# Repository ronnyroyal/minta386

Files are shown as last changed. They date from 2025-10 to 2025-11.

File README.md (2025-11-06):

# Minta 386 memory board

This is a reverse engineered memory board for the Minta Technologies PCB-305 Mainboard.  
https://theretroweb.com/motherboards/s/minta-technologies-co-pcb-305  
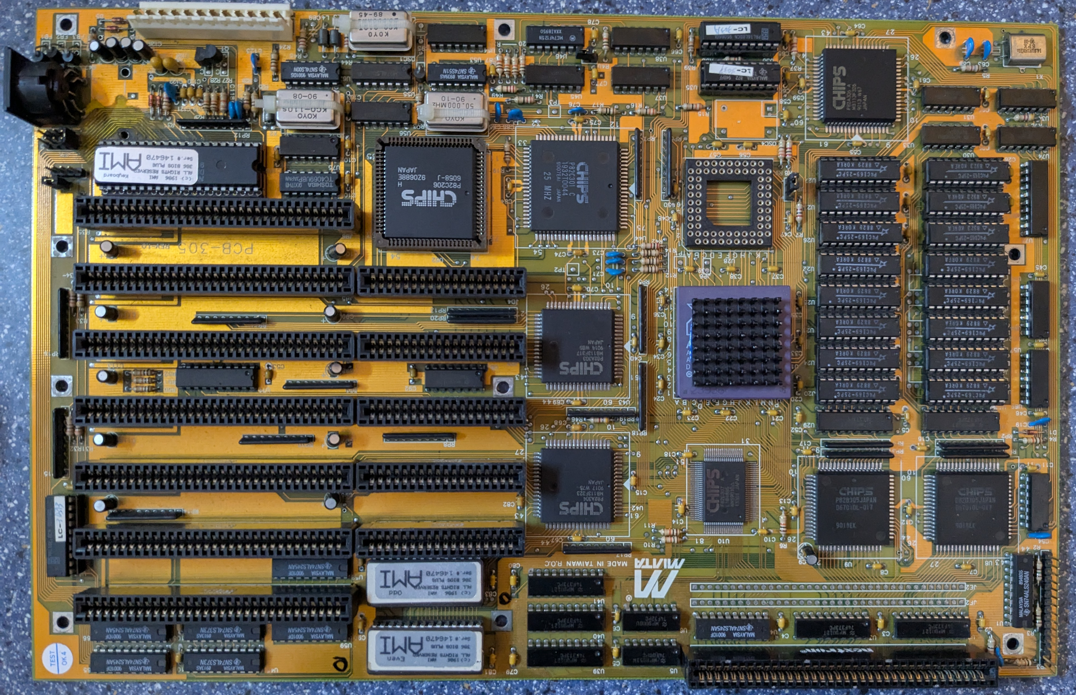
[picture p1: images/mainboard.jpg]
  
I bought this board a while ago missing it's proprietary memory board with the plan to reverse engineer the memory board.   
The memory card was designed with sipp memory in mind as i have a lot of sipp modules, but the spacing also allows for simm sockets to be installed.
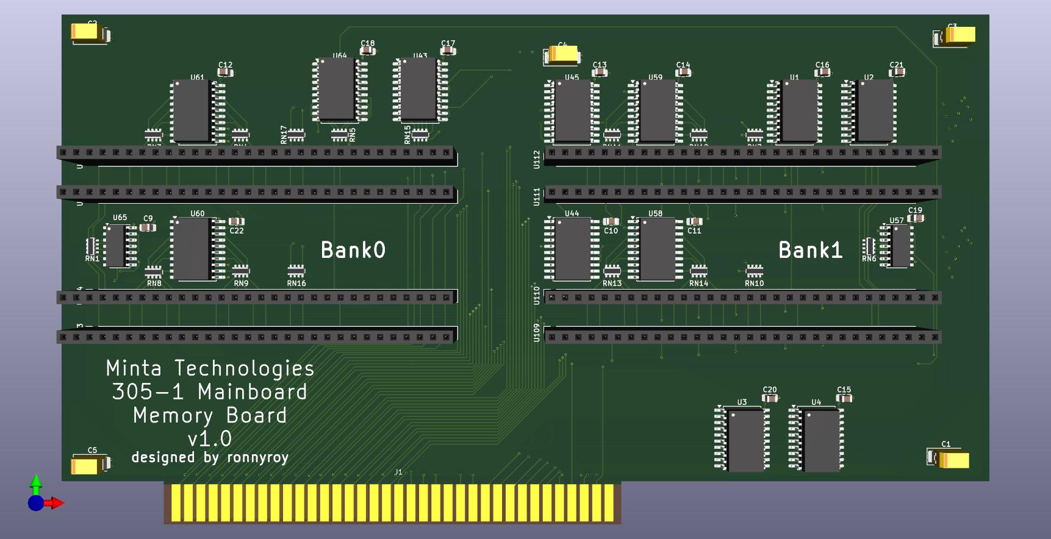
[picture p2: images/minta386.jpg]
 
It can accomodate up to 8 1MB modules with the slot being wired to theoretically support up to 16MB.  
The first PCB revision contains a fault with the parity bit lines being swapped. This is fixed in the provided files.
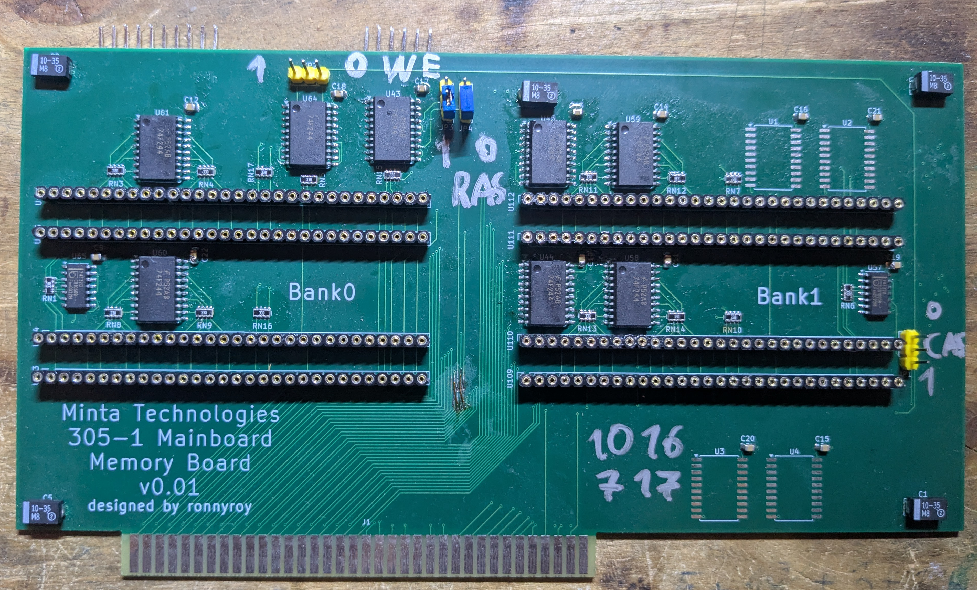
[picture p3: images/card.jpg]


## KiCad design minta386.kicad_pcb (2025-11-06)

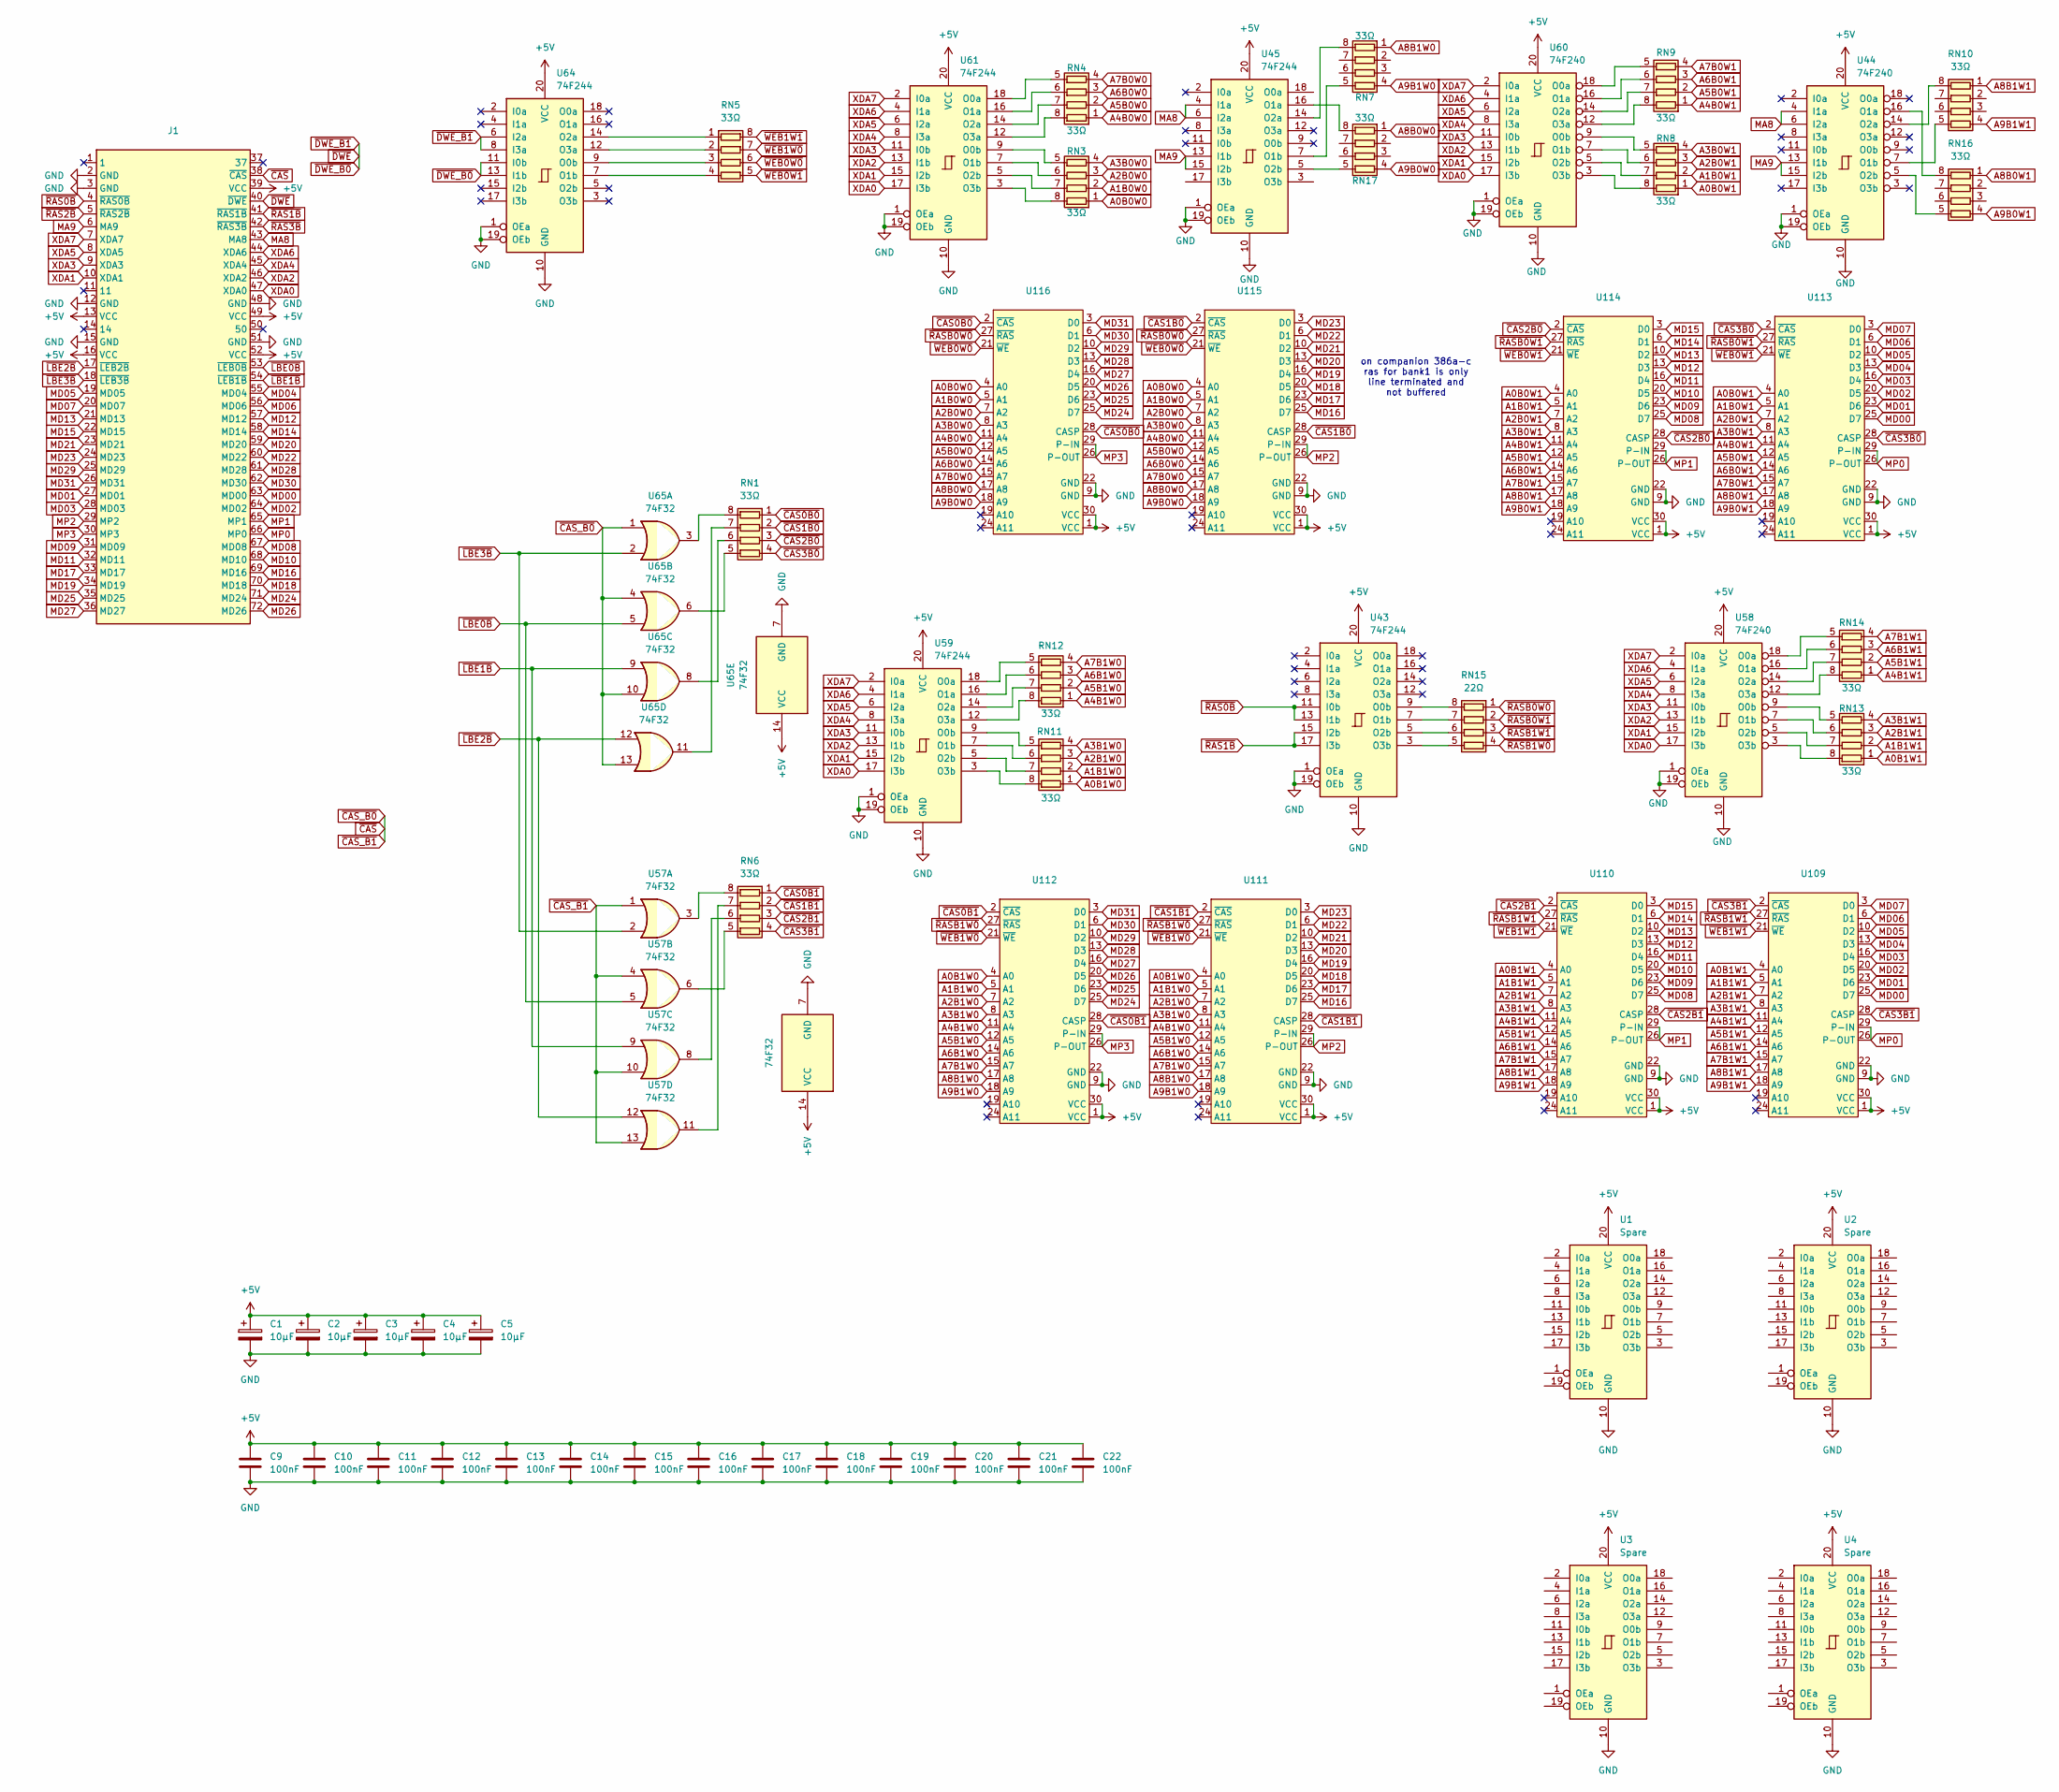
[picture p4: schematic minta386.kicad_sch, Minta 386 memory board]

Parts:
C1, C2, C3, C4, C5: 10µF; CP_EIA-6032-28_Kemet-C_Pad2.25x2.35mm_HandSolder
C9, C10, C11, C12, C13, C14, C15, C16, C17, C18, C19, C20, C21, C22: 100nF; C_0805_2012Metric_Pad1.18x1.45mm_HandSolder
J1: minta_386_memory_bus
RN1, RN3, RN4, RN5, RN6, RN7, RN8, RN9, RN10, RN11, RN12, RN13, RN14, RN16, RN17: 33Ω; R_Array_Concave_4x0603
RN15: 22Ω; R_Array_Concave_4x0603
U1, U2, U3, U4: Spare; SOIC-20W_7.5x12.8mm_P1.27mm
U43, U45, U59, U61, U64: 74F244; SOIC-20W_7.5x12.8mm_P1.27mm
U44, U58, U60: 74F240; SOIC-20W_7.5x12.8mm_P1.27mm
U57, U65: 74F32; SOIC-14_3.9x8.7mm_P1.27mm
U109, U110, U111, U112, U113, U114, U115, U116: PinSocket_1x30_P2.54mm_Vertical

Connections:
+5V: C1.1, C2.1, C3.1, C4.1, C5.1, C9.1, C10.1, C11.1, C12.1, C13.1, C14.1, C15.1, C16.1, C17.1, C18.1, C19.1, C20.1, C21.1, C22.1, J1.13 (VCC), J1.16 (VCC), J1.39 (VCC), J1.49 (VCC), J1.52 (VCC), U1.20 (VCC), U2.20 (VCC), U3.20 (VCC), U4.20 (VCC), U43.20 (VCC), U44.20 (VCC), U45.20 (VCC), U57.14 (VCC), U58.20 (VCC), U59.20 (VCC), U60.20 (VCC), U61.20 (VCC), U64.20 (VCC), U65.14 (VCC), U109.1 (VCC), U109.30 (VCC), U110.1 (VCC), U110.30 (VCC), U111.1 (VCC), U111.30 (VCC), U112.1 (VCC), U112.30 (VCC), U113.1 (VCC), U113.30 (VCC), U114.1 (VCC), U114.30 (VCC), U115.1 (VCC), U115.30 (VCC), U116.1 (VCC), U116.30 (VCC)
A0B0W0: RN3.1 (R1.1), U115.4 (A0), U116.4 (A0)
A0B0W1: RN8.1 (R1.1), U113.4 (A0), U114.4 (A0)
A0B1W0: RN11.1 (R1.1), U111.4 (A0), U112.4 (A0)
A0B1W1: RN13.1 (R1.1), U109.4 (A0), U110.4 (A0)
A1B0W0: RN3.2 (R2.1), U115.5 (A1), U116.5 (A1)
A1B0W1: RN8.2 (R2.1), U113.5 (A1), U114.5 (A1)
A1B1W0: RN11.2 (R2.1), U111.5 (A1), U112.5 (A1)
A1B1W1: RN13.2 (R2.1), U109.5 (A1), U110.5 (A1)
A2B0W0: RN3.3 (R3.1), U115.7 (A2), U116.7 (A2)
A2B0W1: RN8.3 (R3.1), U113.7 (A2), U114.7 (A2)
A2B1W0: RN11.3 (R3.1), U111.7 (A2), U112.7 (A2)
A2B1W1: RN13.3 (R3.1), U109.7 (A2), U110.7 (A2)
A3B0W0: RN3.4 (R4.1), U115.8 (A3), U116.8 (A3)
A3B0W1: RN8.4 (R4.1), U113.8 (A3), U114.8 (A3)
A3B1W0: RN11.4 (R4.1), U111.8 (A3), U112.8 (A3)
A3B1W1: RN13.4 (R4.1), U109.8 (A3), U110.8 (A3)
A4B0W0: RN4.1 (R1.1), U115.11 (A4), U116.11 (A4)
A4B0W1: RN9.1 (R1.1), U113.11 (A4), U114.11 (A4)
A4B1W0: RN12.1 (R1.1), U111.11 (A4), U112.11 (A4)
A4B1W1: RN14.1 (R1.1), U109.11 (A4), U110.11 (A4)
A5B0W0: RN4.2 (R2.1), U115.12 (A5), U116.12 (A5)
A5B0W1: RN9.2 (R2.1), U113.12 (A5), U114.12 (A5)
A5B1W0: RN12.2 (R2.1), U111.12 (A5), U112.12 (A5)
A5B1W1: RN14.2 (R2.1), U109.12 (A5), U110.12 (A5)
A6B0W0: RN4.3 (R3.1), U115.14 (A6), U116.14 (A6)
A6B0W1: RN9.3 (R3.1), U113.14 (A6), U114.14 (A6)
A6B1W0: RN12.3 (R3.1), U111.14 (A6), U112.14 (A6)
A6B1W1: RN14.3 (R3.1), U109.14 (A6), U110.14 (A6)
A7B0W0: RN4.4 (R4.1), U115.15 (A7), U116.15 (A7)
A7B0W1: RN9.4 (R4.1), U113.15 (A7), U114.15 (A7)
A7B1W0: RN12.4 (R4.1), U111.15 (A7), U112.15 (A7)
A7B1W1: RN14.4 (R4.1), U109.15 (A7), U110.15 (A7)
A8B0W0: RN17.1 (R1.1), U115.17 (A8), U116.17 (A8)
A8B0W1: RN16.1 (R1.1), U113.17 (A8), U114.17 (A8)
A8B1W0: RN7.1 (R1.1), U111.17 (A8), U112.17 (A8)
A8B1W1: RN10.1 (R1.1), U109.17 (A8), U110.17 (A8)
A9B0W0: RN17.4 (R4.1), U115.18 (A9), U116.18 (A9)
A9B0W1: RN16.4 (R4.1), U113.18 (A9), U114.18 (A9)
A9B1W0: RN7.4 (R4.1), U111.18 (A9), U112.18 (A9)
A9B1W1: RN10.4 (R4.1), U109.18 (A9), U110.18 (A9)
GND: C1.2, C2.2, C3.2, C4.2, C5.2, C9.2, C10.2, C11.2, C12.2, C13.2, C14.2, C15.2, C16.2, C17.2, C18.2, C19.2, C20.2, C21.2, C22.2, J1.2 (GND), J1.3 (GND), J1.12 (GND), J1.15 (GND), J1.48 (GND), J1.51 (GND), U1.10 (GND), U2.10 (GND), U3.10 (GND), U4.10 (GND), U43.1 (OEa), U43.10 (GND), U43.19 (OEb), U44.1 (OEa), U44.10 (GND), U44.19 (OEb), U45.1 (OEa), U45.10 (GND), U45.19 (OEb), U57.7 (GND), U58.1 (OEa), U58.10 (GND), U58.19 (OEb), U59.1 (OEa), U59.10 (GND), U59.19 (OEb), U60.1 (OEa), U60.10 (GND), U60.19 (OEb), U61.1 (OEa), U61.10 (GND), U61.19 (OEb), U64.1 (OEa), U64.10 (GND), U64.19 (OEb), U65.7 (GND), U109.9 (GND), U109.22 (GND), U110.9 (GND), U110.22 (GND), U111.9 (GND), U111.22 (GND), U112.9 (GND), U112.22 (GND), U113.9 (GND), U113.22 (GND), U114.9 (GND), U114.22 (GND), U115.9 (GND), U115.22 (GND), U116.9 (GND), U116.22 (GND)
MA8: J1.43 (MA8), U44.4 (I1a), U44.6 (I2a), U45.4 (I1a), U45.6 (I2a)
MA9: J1.6 (MA9), U44.13 (I1b), U44.15 (I2b), U45.13 (I1b), U45.15 (I2b)
MD00: J1.63 (MD00), U109.25 (D7), U113.25 (D7)
MD01: J1.27 (MD01), U109.23 (D6), U113.23 (D6)
MD02: J1.64 (MD02), U109.20 (D5), U113.20 (D5)
MD03: J1.28 (MD03), U109.16 (D4), U113.16 (D4)
MD04: J1.55 (MD04), U109.13 (D3), U113.13 (D3)
MD05: J1.19 (MD05), U109.10 (D2), U113.10 (D2)
MD06: J1.56 (MD06), U109.6 (D1), U113.6 (D1)
MD07: J1.20 (MD07), U109.3 (D0), U113.3 (D0)
MD08: J1.67 (MD08), U110.25 (D7), U114.25 (D7)
MD09: J1.31 (MD09), U110.23 (D6), U114.23 (D6)
MD10: J1.68 (MD10), U110.20 (D5), U114.20 (D5)
MD11: J1.32 (MD11), U110.16 (D4), U114.16 (D4)
MD12: J1.57 (MD12), U110.13 (D3), U114.13 (D3)
MD13: J1.21 (MD13), U110.10 (D2), U114.10 (D2)
MD14: J1.58 (MD14), U110.6 (D1), U114.6 (D1)
MD15: J1.22 (MD15), U110.3 (D0), U114.3 (D0)
MD16: J1.69 (MD16), U111.25 (D7), U115.25 (D7)
MD17: J1.33 (MD17), U111.23 (D6), U115.23 (D6)
MD18: J1.70 (MD18), U111.20 (D5), U115.20 (D5)
MD19: J1.34 (MD19), U111.16 (D4), U115.16 (D4)
MD20: J1.59 (MD20), U111.13 (D3), U115.13 (D3)
MD21: J1.23 (MD21), U111.10 (D2), U115.10 (D2)
MD22: J1.60 (MD22), U111.6 (D1), U115.6 (D1)
MD23: J1.24 (MD23), U111.3 (D0), U115.3 (D0)
MD24: J1.71 (MD24), U112.25 (D7), U116.25 (D7)
MD25: J1.35 (MD25), U112.23 (D6), U116.23 (D6)
MD26: J1.72 (MD26), U112.20 (D5), U116.20 (D5)
MD27: J1.36 (MD27), U112.16 (D4), U116.16 (D4)
MD28: J1.61 (MD28), U112.13 (D3), U116.13 (D3)
MD29: J1.25 (MD29), U112.10 (D2), U116.10 (D2)
MD30: J1.62 (MD30), U112.6 (D1), U116.6 (D1)
MD31: J1.26 (MD31), U112.3 (D0), U116.3 (D0)
MP0: J1.66 (MP0), U109.26 (P-OUT), U109.29 (P-IN), U113.26 (P-OUT), U113.29 (P-IN)
MP1: J1.65 (MP1), U110.26 (P-OUT), U110.29 (P-IN), U114.26 (P-OUT), U114.29 (P-IN)
MP2: J1.29 (MP2), U111.26 (P-OUT), U111.29 (P-IN), U115.26 (P-OUT), U115.29 (P-IN)
MP3: J1.30 (MP3), U112.26 (P-OUT), U112.29 (P-IN), U116.26 (P-OUT), U116.29 (P-IN)
unnamed: RN1.8 (R1.2), U65.3
unnamed: RN1.7 (R2.2), U65.11
unnamed: RN1.6 (R3.2), U65.8
unnamed: RN1.5 (R4.2), U65.6
unnamed: RN3.8 (R1.2), U61.3 (O3b)
unnamed: RN3.7 (R2.2), U61.5 (O2b)
unnamed: RN3.6 (R3.2), U61.7 (O1b)
unnamed: RN3.5 (R4.2), U61.9 (O0b)
unnamed: RN4.8 (R1.2), U61.12 (O3a)
unnamed: RN4.7 (R2.2), U61.14 (O2a)
unnamed: RN4.6 (R3.2), U61.16 (O1a)
unnamed: RN4.5 (R4.2), U61.18 (O0a)
unnamed: RN5.1 (R1.1), U64.14 (O2a)
unnamed: RN5.2 (R2.1), U64.12 (O3a)
unnamed: RN5.3 (R3.1), U64.9 (O0b)
unnamed: RN5.4 (R4.1), U64.7 (O1b)
unnamed: RN6.8 (R1.2), U57.3
unnamed: RN6.7 (R2.2), U57.11
unnamed: RN6.6 (R3.2), U57.8
unnamed: RN6.5 (R4.2), U57.6
unnamed: RN7.8 (R1.2), U45.14 (O2a)
unnamed: RN7.5 (R4.2), U45.7 (O1b)
unnamed: RN8.8 (R1.2), U60.3 (O3b)
unnamed: RN8.7 (R2.2), U60.5 (O2b)
unnamed: RN8.6 (R3.2), U60.7 (O1b)
unnamed: RN8.5 (R4.2), U60.9 (O0b)
unnamed: RN9.8 (R1.2), U60.12 (O3a)
unnamed: RN9.7 (R2.2), U60.14 (O2a)
unnamed: RN9.6 (R3.2), U60.16 (O1a)
unnamed: RN9.5 (R4.2), U60.18 (O0a)
unnamed: RN10.8 (R1.2), U44.14 (O2a)
unnamed: RN10.5 (R4.2), U44.7 (O1b)
unnamed: RN11.8 (R1.2), U59.3 (O3b)
unnamed: RN11.7 (R2.2), U59.5 (O2b)
unnamed: RN11.6 (R3.2), U59.7 (O1b)
unnamed: RN11.5 (R4.2), U59.9 (O0b)
unnamed: RN12.8 (R1.2), U59.12 (O3a)
unnamed: RN12.7 (R2.2), U59.14 (O2a)
unnamed: RN12.6 (R3.2), U59.16 (O1a)
unnamed: RN12.5 (R4.2), U59.18 (O0a)
unnamed: RN13.8 (R1.2), U58.3 (O3b)
unnamed: RN13.7 (R2.2), U58.5 (O2b)
unnamed: RN13.6 (R3.2), U58.7 (O1b)
unnamed: RN13.5 (R4.2), U58.9 (O0b)
unnamed: RN14.8 (R1.2), U58.12 (O3a)
unnamed: RN14.7 (R2.2), U58.14 (O2a)
unnamed: RN14.6 (R3.2), U58.16 (O1a)
unnamed: RN14.5 (R4.2), U58.18 (O0a)
unnamed: RN15.8 (R1.2), U43.9 (O0b)
unnamed: RN15.7 (R2.2), U43.7 (O1b)
unnamed: RN15.6 (R3.2), U43.5 (O2b)
unnamed: RN15.5 (R4.2), U43.3 (O3b)
unnamed: RN16.8 (R1.2), U44.16 (O1a)
unnamed: RN16.5 (R4.2), U44.5 (O2b)
unnamed: RN17.8 (R1.2), U45.16 (O1a)
unnamed: RN17.5 (R4.2), U45.5 (O2b)
XDA0: J1.47 (XDA0), U58.17 (I3b), U59.17 (I3b), U60.17 (I3b), U61.17 (I3b)
XDA1: J1.10 (XDA1), U58.15 (I2b), U59.15 (I2b), U60.15 (I2b), U61.15 (I2b)
XDA2: J1.46 (XDA2), U58.13 (I1b), U59.13 (I1b), U60.13 (I1b), U61.13 (I1b)
XDA3: J1.9 (XDA3), U58.11 (I0b), U59.11 (I0b), U60.11 (I0b), U61.11 (I0b)
XDA4: J1.45 (XDA4), U58.8 (I3a), U59.8 (I3a), U60.8 (I3a), U61.8 (I3a)
XDA5: J1.8 (XDA5), U58.6 (I2a), U59.6 (I2a), U60.6 (I2a), U61.6 (I2a)
XDA6: J1.44 (XDA6), U58.4 (I1a), U59.4 (I1a), U60.4 (I1a), U61.4 (I1a)
XDA7: J1.7 (XDA7), U58.2 (I0a), U59.2 (I0a), U60.2 (I0a), U61.2 (I0a)
~CAS0B0: RN1.1 (R1.1), U116.2 (~CAS), U116.28 (CASP)
~CAS0B1: RN6.1 (R1.1), U112.2 (~CAS), U112.28 (CASP)
~CAS1B0: RN1.2 (R2.1), U115.2 (~CAS), U115.28 (CASP)
~CAS1B1: RN6.2 (R2.1), U111.2 (~CAS), U111.28 (CASP)
~CAS2B0: RN1.3 (R3.1), U114.2 (~CAS), U114.28 (CASP)
~CAS2B1: RN6.3 (R3.1), U110.2 (~CAS), U110.28 (CASP)
~CAS3B0: RN1.4 (R4.1), U113.2 (~CAS), U113.28 (CASP)
~CAS3B1: RN6.4 (R4.1), U109.2 (~CAS), U109.28 (CASP)
~CAS_B0: J1.38 (~CAS), U57.1, U57.4, U57.10, U57.13, U65.1, U65.4, U65.10, U65.13
~DWE_B0: J1.40 (~DWE), U64.6 (I2a), U64.8 (I3a), U64.11 (I0b), U64.13 (I1b)
~LBE0B: J1.53 (~LEB0B), U57.5, U65.5
~LBE1B: J1.54 (~LEB1B), U57.9, U65.9
~LBE2B: J1.17 (~LEB2B), U57.12, U65.12
~LBE3B: J1.18 (~LEB3B), U57.2, U65.2
~RAS0B: J1.4 (~RAS0B), U43.11 (I0b), U43.13 (I1b)
~RAS1B: J1.41 (~RAS1B), U43.15 (I2b), U43.17 (I3b)
~RAS2B: J1.5 (~RAS2B)
~RAS3B: J1.42 (~RAS3B)
~RASB0W0: RN15.1 (R1.1), U115.27 (~RAS), U116.27 (~RAS)
~RASB0W1: RN15.2 (R2.1), U113.27 (~RAS), U114.27 (~RAS)
~RASB1W0: RN15.4 (R4.1), U111.27 (~RAS), U112.27 (~RAS)
~RASB1W1: RN15.3 (R3.1), U109.27 (~RAS), U110.27 (~RAS)
~WEB0W0: RN5.6 (R3.2), U115.21 (~WE), U116.21 (~WE)
~WEB0W1: RN5.5 (R4.2), U113.21 (~WE), U114.21 (~WE)
~WEB1W0: RN5.7 (R2.2), U111.21 (~WE), U112.21 (~WE)
~WEB1W1: RN5.8 (R1.2), U109.21 (~WE), U110.21 (~WE)

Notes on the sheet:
on companion 386a-c ras for bank1 is only line terminated and not buffered

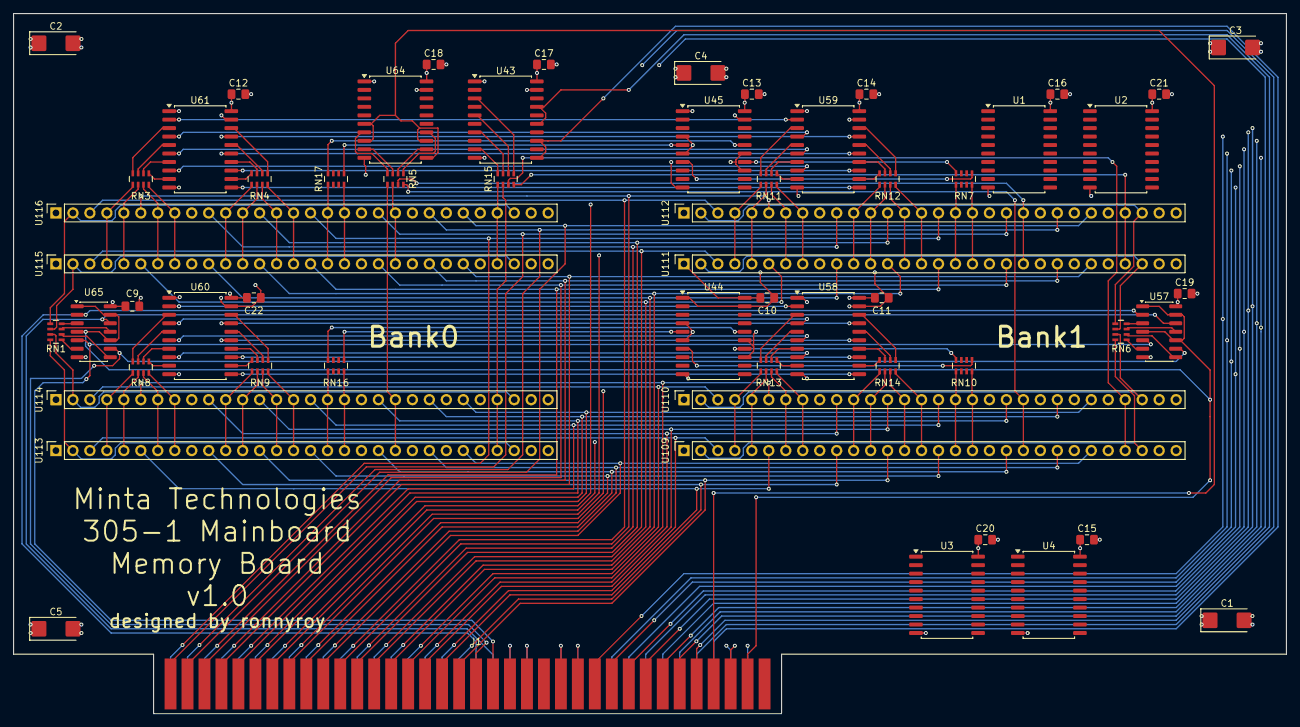
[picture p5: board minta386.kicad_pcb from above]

Board: 4 copper layers, 190.5 x 104.8 mm, 58 parts (0 on the bottom side), 168 nets.

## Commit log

2025-10-25 Add initial protoype PCB files with parity bit error fixed
    [minta386.kicad_pcb, minta386.kicad_sch]
2025-10-25 Create README for Minta 386 memory board project
    Added a README file for the Minta 386 memory board project, detailing its purpose and specifications.
2025-11-06 slight board chnages for rev 1.0
    [minta386.kicad_pcb, minta386.kicad_sch]
